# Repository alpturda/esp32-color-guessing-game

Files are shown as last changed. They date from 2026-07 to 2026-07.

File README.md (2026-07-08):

# ESP32 Color Guessing Game

[🇹🇷 Türkçe README](README_TR.md)

ESP32 Color Guessing Game is an embedded game project developed using an ESP32 microcontroller, an ST7789 TFT display, a rotary encoder, and a custom 3D printed enclosure.

The game is inspired by code-breaking logic games. The player tries to guess a hidden 4-color code selected from an 8-color palette. Each guess is displayed on the TFT screen, and the system provides visual feedback for correct colors and correct positions.

## Working Prototype

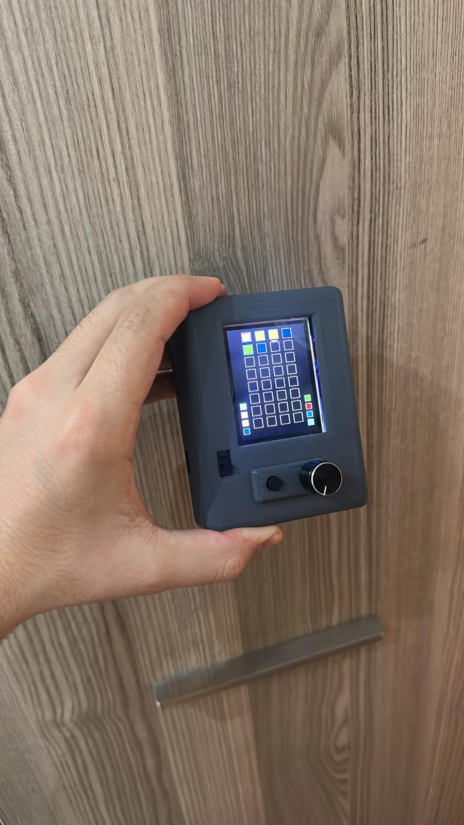
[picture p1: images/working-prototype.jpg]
Working Prototype


## Features

- ESP32 based embedded game system
- ST7789 240x320 TFT display interface
- Rotary encoder based user input
- 8-color selectable palette
- 4-slot hidden color code
- Maximum 8 attempts
- Guess history displayed on screen
- Visual feedback system
- State machine based game flow
- Custom 3D printed enclosure
- Portable Li-ion battery powered design

## Hardware Used

- ESP32 development board
- ST7789 240x320 TFT display module
- Rotary encoder with push button
- Push button for back/delete function
- 3.7V Li-ion battery
- Li-ion battery charging module
- 3.3V voltage regulator
- Jumper wires
- Custom 3D printed case

## Power Supply

The project is powered by a 3.7V Li-ion battery.

A charging module is used for battery charging, and a voltage regulator is used to provide a stable 3.3V supply for the ESP32 and the circuit.

### Power Components

- 3.7V Li-ion battery
- Li-ion battery charging module
- 3.3V voltage regulator

> Note: Power wiring may vary depending on the ESP32 development board, charging module, and regulator used.

## Pin Connections

| Component | ESP32 Pin |
|---|---|
| TFT CS | GPIO 5 |
| TFT DC | GPIO 2 |
| TFT RST | GPIO 4 |
| TFT SCK / SCL | GPIO 18 |
| TFT MOSI / SDA | GPIO 23 |
| Encoder A / CLK | GPIO 32 |
| Encoder B / DT | GPIO 33 |
| Encoder Push / SW | GPIO 25 |
| Back Button | GPIO 26 |

> Note: ST7789 display module pin names may vary depending on the module version. Some modules label SPI pins as SCL/SDA, while others use SCK/MOSI.

## Wiring Diagram

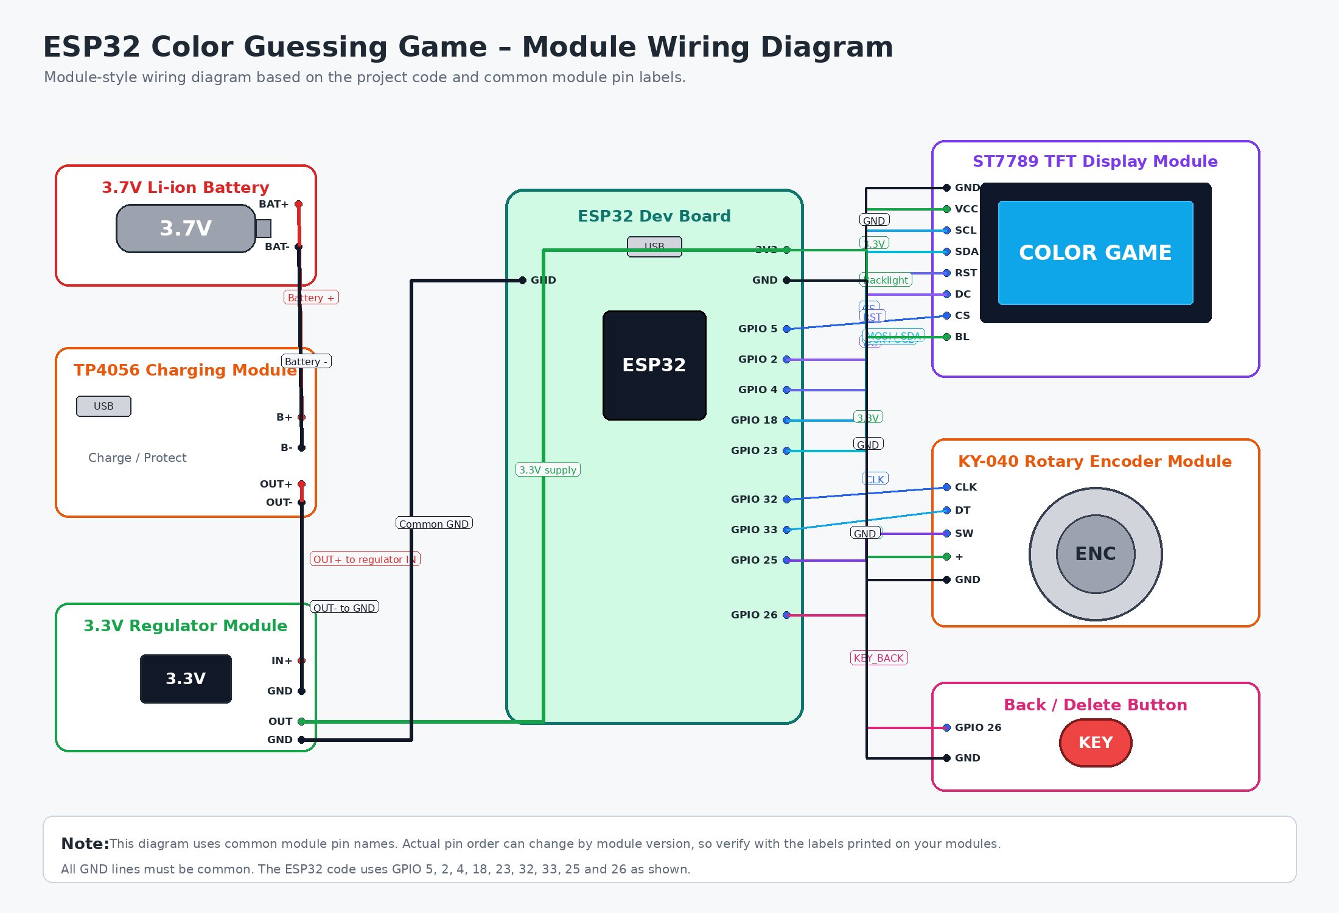
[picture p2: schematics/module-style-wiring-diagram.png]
Module Style Wiring Diagram


## Game Logic

The system generates a random 4-color secret code at the beginning of each game.

The player selects colors using the rotary encoder and confirms each selection by pressing the encoder button.

After each 4-color guess, the system compares the guess with the secret code and provides visual feedback:

- Green: Correct color and correct position
- Yellow: Correct color but wrong position
- White / Empty: No match

The player wins if all 4 colors are guessed in the correct positions within 8 attempts. If the player cannot find the correct code within 8 attempts, the secret code is shown on the screen.

## 3D Printed Enclosure

A custom enclosure was designed and printed for this project.

The enclosure was created to hold the ESP32, ST7789 TFT display, rotary encoder, back/delete button, power switch, battery, charging module, and voltage regulator in a compact prototype form.

### 3D Model Overview

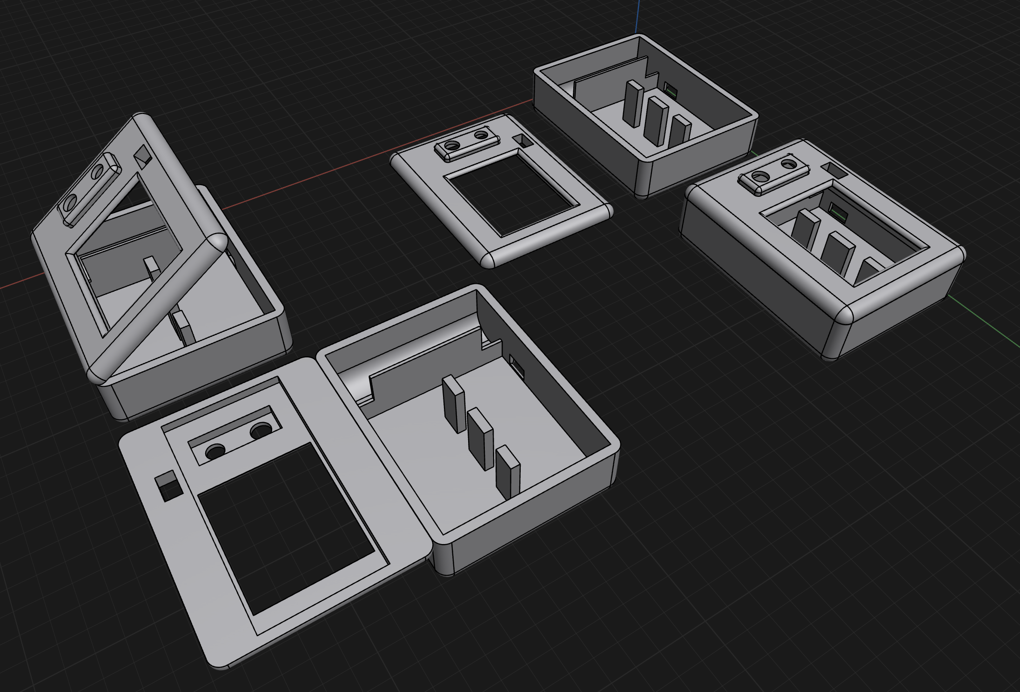
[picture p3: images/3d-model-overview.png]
3D Model Overview


### Enclosure Front View

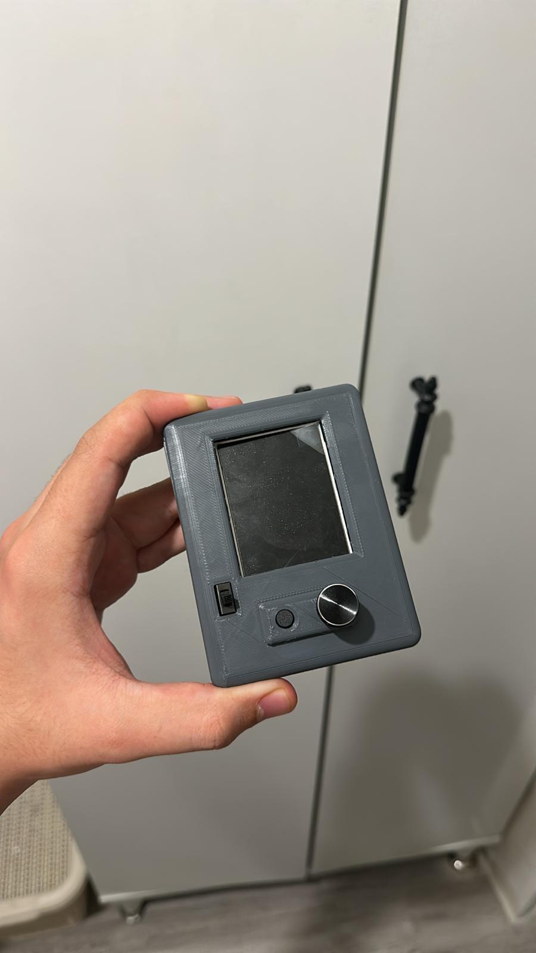
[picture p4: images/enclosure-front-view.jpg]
Enclosure Front View


### Enclosure Side View

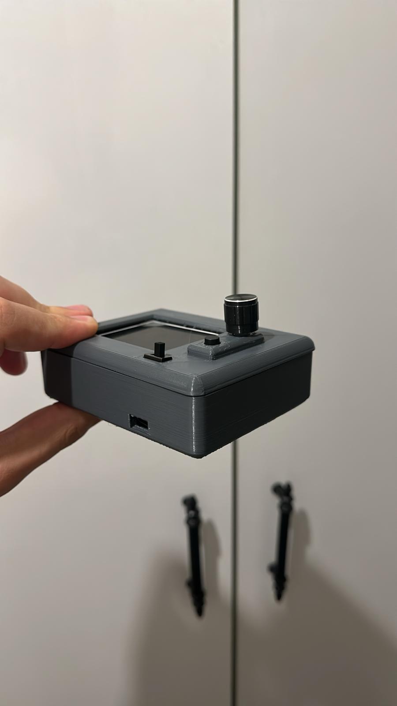
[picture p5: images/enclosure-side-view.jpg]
Enclosure Side View


## 3D Model Files

The enclosure consists of two main parts:

- `case` – main body of the enclosure
- `cover` – front cover / top panel

Both STL and STEP files are provided.

### Case

- STL: `3d-models/case/stl-files/case.stl`
- STEP: `3d-models/case/step-files/case.step`

### Cover

- STL: `3d-models/cover/stl-files/cover.stl`
- STEP: `3d-models/cover/step-files/cover.step`

STL files are provided for 3D printing.

STEP files are provided for CAD editing and modification.

## Technologies Used

- ESP32
- Arduino IDE
- C/C++
- Adafruit GFX Library
- Adafruit ST7789 Library
- SPI Communication
- Rotary Encoder Input
- Embedded UI Design
- 3D Modeling
- 3D Printing

## Project Structure

```text
esp32-color-guessing-game
├── 3d-models
│   ├── case
│   │   ├── step-files
│   │   │   └── case.step
│   │   └── stl-files
│   │       └── case.stl
│   │
│   └── cover
│       ├── step-files
│       │   └── cover.step
│       └── stl-files
│           └── cover.stl
│
├── images
│   ├── 3d-model-overview.png
│   ├── enclosure-front-view.jpg
│   ├── enclosure-side-view.jpg
│   └── working-prototype.jpg
│
├── schematics
│   └── module-style-wiring-diagram.png
│
├── src
│   └── esp32-color-guessing-game
│       └── esp32-color-guessing-game.ino
│
├── LICENSE
├── README.md
└── README_TR.md
```
## Project Status

This project was developed as a working embedded systems prototype.

The game logic, display interface, rotary encoder input, custom enclosure, and portable power structure were designed and implemented as part of the project.

## Author

Alp Çağatay Turda

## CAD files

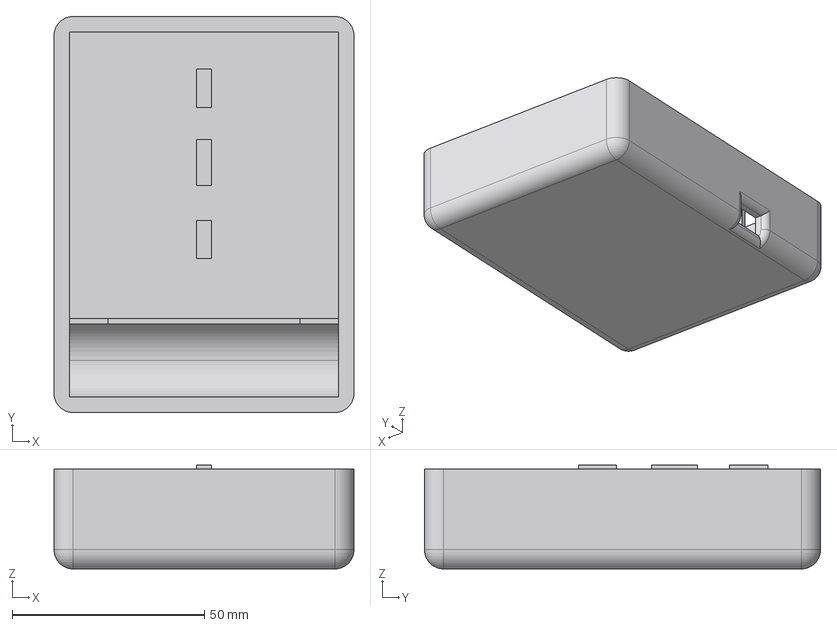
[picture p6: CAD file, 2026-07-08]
3d-models/case/step-files/case.step
78.0 x 103.0 x 27.0 mm

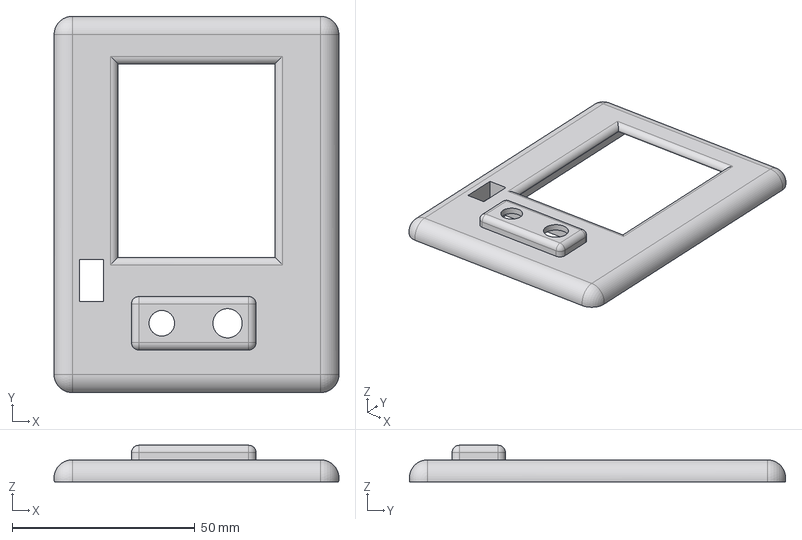
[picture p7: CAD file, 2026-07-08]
3d-models/cover/step-files/cover.step
78.0 x 103.0 x 10.0 mm

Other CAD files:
3d-models/case/stl-files/case.stl
3d-models/cover/stl-files/cover.stl

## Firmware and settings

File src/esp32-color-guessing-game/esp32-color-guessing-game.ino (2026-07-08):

#include <Adafruit_GFX.h>
#include <Adafruit_ST7789.h>
#include <SPI.h>

// =====================================================
// ESP32 Color Guessing Game
// Hardware: ESP32 + ST7789 TFT Display + Rotary Encoder
// Author: Alp Çağatay Turda
// =====================================================

// --- Pin Definitions ---
#define TFT_CS     5
#define TFT_DC     2
#define TFT_RST    4

#define ENC_A     32
#define ENC_B     33
#define ENC_PUSH  25
#define KEY_BACK  26

// --- Game Settings ---
#define MAX_ATTEMPTS 8
#define CODE_LENGTH  4
#define NUM_COLORS   8

// --- Color Palette ---
uint16_t palette[NUM_COLORS] = {
  ST77XX_RED,
  ST77XX_GREEN,
  ST77XX_BLUE,
  ST77XX_YELLOW,
  ST77XX_MAGENTA,
  ST77XX_CYAN,
  ST77XX_ORANGE,
  0x780F
};

// --- Game State Machine ---
enum GameState {
  INIT,
  DRAW_STATIC_UI,
  INPUT_MOVE,
  CHECK_GUESS,
  UPDATE_UI,
  END_WIN,
  END_LOSE
};

GameState currentState = INIT;

// --- TFT Object ---
Adafruit_ST7789 tft = Adafruit_ST7789(TFT_CS, TFT_DC, TFT_RST);

// --- Game Data ---
int secretCode[CODE_LENGTH];
int currentGuess[CODE_LENGTH];
int guessHistory[MAX_ATTEMPTS][CODE_LENGTH];

// Feedback values:
// -1: Empty
//  0: No match / White
//  1: Correct color, wrong position / Yellow
//  2: Correct color, correct position / Green
int feedbackHistory[MAX_ATTEMPTS][CODE_LENGTH];

int currentAttempt = 0;
int currentSlot = 0;
int selectedColorIdx = 0;

// --- Encoder Variables ---
int lastEncA;

// --- Animation Variables ---
unsigned long lastAnimTime = 0;
bool animState = false;

// --- Display Layout Settings ---
const int boxSize = 28;
const int horizontalGap = 14;
const int verticalStep = 36;
const int startY = 10;

// --- Feedback Indicator Size ---
const int feedbackW = 20;
const int feedbackH = 5;

void setup() {
  pinMode(ENC_A, INPUT_PULLUP);
  pinMode(ENC_B, INPUT_PULLUP);
  pinMode(ENC_PUSH, INPUT_PULLUP);
  pinMode(KEY_BACK, INPUT_PULLUP);

  tft.init(240, 320);
  tft.setRotation(2);
  tft.fillScreen(ST77XX_WHITE);

  lastEncA = digitalRead(ENC_A);

  // Creates a random seed for the secret code
  randomSeed(analogRead(0));
}

void loop() {
  switch (currentState) {
    case INIT:
      generateSecretCode();

      for (int i = 0; i < MAX_ATTEMPTS; i++) {
        for (int j = 0; j < CODE_LENGTH; j++) {
          feedbackHistory[i][j] = -1;
        }
      }

      currentAttempt = 0;
      currentSlot = 0;
      currentState = DRAW_STATIC_UI;
      break;

    case DRAW_STATIC_UI:
      drawBoard();
      drawPalette();
      currentState = INPUT_MOVE;
      break;

    case INPUT_MOVE:
      handleEncoder();
      handleButtons();
      drawActiveSlotAnim();
      break;

    case CHECK_GUESS:
      processGuess();
      break;

    case UPDATE_UI:
      drawBoard();
      drawPalette();

      if (currentAttempt >= MAX_ATTEMPTS) {
        currentState = END_LOSE;
      } else {
        currentState = INPUT_MOVE;
      }
      break;

    case END_WIN:
      showEndGame("YOU WIN!");
      break;

    case END_LOSE:
      showEndGame("GAME OVER!");
      break;
  }
}

// Generates a random secret color code
void generateSecretCode() {
  for (int i = 0; i < CODE_LENGTH; i++) {
    secretCode[i] = random(NUM_COLORS);
  }
}

// Draws the main game board
void drawBoard() {
  tft.fillScreen(ST77XX_WHITE);

  int startX = (240 - (CODE_LENGTH * boxSize + (CODE_LENGTH - 1) * horizontalGap)) / 2;

  for (int i = 0; i < MAX_ATTEMPTS; i++) {
    for (int j = 0; j < CODE_LENGTH; j++) {
      int px = startX + j * (boxSize + horizontalGap);
      int py = startY + i * verticalStep;

      // Draw empty box
      tft.drawRect(px, py, boxSize, boxSize, ST77XX_BLACK);

      if (i < currentAttempt) {
        // Draw previous guess color
        tft.fillRect(px + 2, py + 2, boxSize - 4, boxSize - 4, palette[guessHistory[i][j]]);

        // Draw feedback indicator under each box
        uint16_t feedCol = ST77XX_WHITE;

        if (feedbackHistory[i][j] == 2) {
          feedCol = ST77XX_GREEN;
        } else if (feedbackHistory[i][j] == 1) {
          feedCol = ST77XX_YELLOW;
        }

        int feedX = px + (boxSize - feedbackW) / 2;
        int feedY = py + boxSize + 2;

        tft.fillRect(feedX, feedY, feedbackW, feedbackH, feedCol);
        tft.drawRect(feedX, feedY, feedbackW, feedbackH, feedCol);
      }

      else if (i == currentAttempt && j < currentSlot) {
        // Draw already selected colors in the current row
        tft.fillRect(px + 2, py + 2, boxSize - 4, boxSize - 4, palette[currentGuess[j]]);
      }
    }
  }
}

// Draws the color palette on both sides of the screen
void drawPalette() {
  int pSize = 18;
  int gap = 6;
  int paletteStartY = 320 - (4 * (pSize + gap)) - 10;

  for (int i = 0; i < 4; i++) {
    // Left side colors
    tft.fillRect(10, paletteStartY + i * (pSize + gap), pSize, pSize, palette[i]);
    tft.drawRect(10, paletteStartY + i * (pSize + gap), pSize, pSize, ST77XX_BLACK);

    // Right side colors
    tft.fillRect(240 - pSize - 10, paletteStartY + i * (pSize + gap), pSize, pSize, palette[i + 4]);
    tft.drawRect(240 - pSize - 10, paletteStartY + i * (pSize + gap), pSize, pSize, ST77XX_BLACK);
  }
}

// Reads rotary encoder movement and changes selected color
void handleEncoder() {
  int valA = digitalRead(ENC_A);

  if (valA != lastEncA && valA == LOW) {
    if (digitalRead(ENC_B) != valA) {
      selectedColorIdx = (selectedColorIdx + 1) % NUM_COLORS;
    } else {
      selectedColorIdx = (selectedColorIdx - 1 + NUM_COLORS) % NUM_COLORS;
    }
  }

  lastEncA = valA;
}

// Handles encoder push button and back button
void handleButtons() {
  if (digitalRead(ENC_PUSH) == LOW) {
    int startX = (240 - (CODE_LENGTH * boxSize + (CODE_LENGTH - 1) * horizontalGap)) / 2;
    int px = startX + currentSlot * (boxSize + horizontalGap);
    int py = startY + currentAttempt * verticalStep;

    // Draw selected color in the active slot
    tft.fillRect(px + 2, py + 2, boxSize - 4, boxSize - 4, palette[selectedColorIdx]);

    delay(250);

    currentGuess[currentSlot] = selectedColorIdx;
    currentSlot++;

    if (currentSlot >= CODE_LENGTH) {
      currentState = CHECK_GUESS;
    }
  }

  if (digitalRead(KEY_BACK) == LOW) {
    delay(250);

    if (currentSlot > 0) {
      currentSlot--;

      int startX = (240 - (CODE_LENGTH * boxSize + (CODE_LENGTH - 1) * horizontalGap)) / 2;
      int px = startX + currentSlot * (boxSize + horizontalGap);
      int py = startY + currentAttempt * verticalStep;

      // Clear the last selected slot
      tft.fillRect(px + 2, py + 2, boxSize - 4, boxSize - 4, ST77XX_WHITE);
    }
  }
}

// Checks the current guess and calculates feedback
void processGuess() {
  bool usedSecret[CODE_LENGTH] = {false};
  bool usedGuess[CODE_LENGTH] = {false};

  int results[CODE_LENGTH] = {0};
  int correctCount = 0;

  // First pass:
  // Checks correct color in the correct position
  for (int i = 0; i < CODE_LENGTH; i++) {
    if (currentGuess[i] == secretCode[i]) {
      results[i] = 2;
      usedSecret[i] = true;
      usedGuess[i] = true;
      correctCount++;
    }
  }

  // Second pass:
  // Checks correct color in the wrong position
  for (int i = 0; i < CODE_LENGTH; i++) {
    if (usedGuess[i]) {
      continue;
    }

    for (int j = 0; j < CODE_LENGTH; j++) {
      if (!usedSecret[j] && currentGuess[i] == secretCode[j]) {
        results[i] = 1;
        usedSecret[j] = true;
        break;
      }
    }
  }

  // Saves current guess and feedback to history
  for (int i = 0; i < CODE_LENGTH; i++) {
    guessHistory[currentAttempt][i] = currentGuess[i];
    feedbackHistory[currentAttempt][i] = results[i];
  }

  currentAttempt++;
  currentSlot = 0;

  if (correctCount == CODE_LENGTH) {
    currentState = END_WIN;
  } else {
    currentState = UPDATE_UI;
  }

  delay(500);
}

// Blinks the active slot with the currently selected color
void drawActiveSlotAnim() {
  if (millis() - lastAnimTime > 300) {
    lastAnimTime = millis();
    animState = !animState;

    int startX = (240 - (CODE_LENGTH * boxSize + (CODE_LENGTH - 1) * horizontalGap)) / 2;
    int px = startX + currentSlot * (boxSize + horizontalGap);
    int py = startY + currentAttempt * verticalStep;

    tft.fillRect(
      px + 2,
      py + 2,
      boxSize - 4,
      boxSize - 4,
      animState ? palette[selectedColorIdx] : ST77XX_WHITE
    );
  }
}

// Shows win or lose screen and restarts the game
void showEndGame(String msg) {
  tft.fillRect(30, 100, 180, 110, ST77XX_WHITE);
  tft.drawRect(30, 100, 180, 110, ST77XX_BLACK);

  tft.setTextColor(ST77XX_BLACK);
  tft.setTextSize(2);
  tft.setCursor(65, 120);
  tft.print(msg);

  // Shows the secret code at the end of the game
  for (int i = 0; i < CODE_LENGTH; i++) {
    tft.fillRect(60 + i * 35, 165, 25, 25, palette[secretCode[i]]);
  }

  delay(6000);

  currentState = INIT;
}

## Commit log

2026-07-08 Create schematics folder
2026-07-08 Add module-style wiring diagram
2026-07-08 Add 3D model files
    [case.step, case.stl, cover.step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]
